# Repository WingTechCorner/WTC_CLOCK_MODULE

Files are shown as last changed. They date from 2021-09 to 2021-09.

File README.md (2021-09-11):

# WTC_CLOCK_MODULE

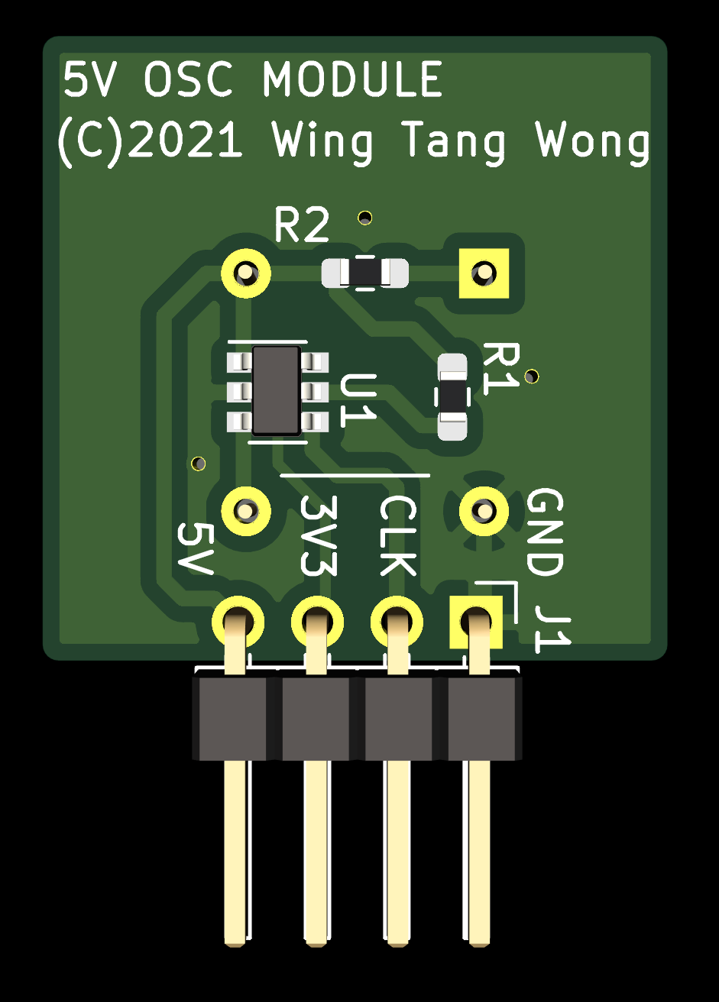
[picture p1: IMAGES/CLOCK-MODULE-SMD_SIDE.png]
SMD Side of Clock Module


# Project Purpose

* Make use of existing components I had in stock. In this case, a bunch of 40Mhz PLE(Plextronics) DIP-8, 4pin oscillators.
* Do voltage conversion from whatever the OSC uses to whatever the mainboard expects/users.
* Keep the footprint small.
* Use this as a sort of re-usable module going forward.

# Parts

| Part Count | Part Name | Package | Part | Usage | Notes |
| :----: | :---- | :---- | :---- | :---- | :---- |
| 1 | SN74LVC1T45 | SOT-23-6 | Single Channel Bidirectional Level Shifter | Takes the OSC clk_out and brings the voltage down to lower voltage. | 22 Ohm resistor has the DIR fixed so A goes to B only. |
| 2 | C23345 (LCSC Part Number) | 0603 SMD | 22 Ohm Resistor | Bridges signal pins to VCC | |
| 1 | PLE-SQ3300-40.00Mhz OSC | PDIP-8, 4pins, shortcan | 40Mhz 5V OSC | Plextronic's legacy/obsolete 40Mhz oscillator. | Generates a 5V, 40Mhz clock signal. Enable tied to VCC via resistor. Output goes to SN74LVC1T45 to have voltage reduced. |
| 1 | 1x4 header | 2.54mm 1x4 | Right angle male header 4 pins | Interface with parent module to provide a clock signal at the desired voltage levels. | Provides a "standard" way for me to add a clock source to another project board. Makes clock sources interchangable and/or re-usable. |

The assumption regarding the pinout of the OSC:

| Pin | Function |
| :-----: | :--- |
| 1 | Enable/Disable (current limit resistor tied to 5V) |
| 4 | GND |
| 5 | Clock Output |
| 8 | VCC (5V) |

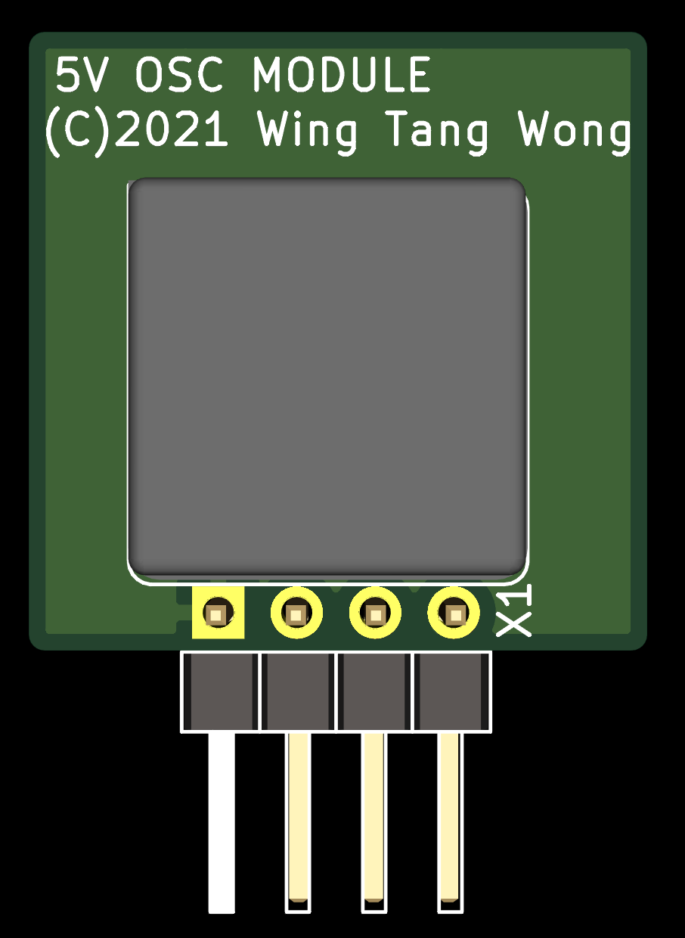
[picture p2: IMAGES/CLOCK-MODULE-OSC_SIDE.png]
OSC CAN Side of Clock Module


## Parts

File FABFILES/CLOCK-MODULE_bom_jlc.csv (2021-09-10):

Comment | Designator | Footprint | LCSC Part #
Conn_01x04 | J1 | PinHeader_1x04_P2.54mm_Horizontal | no_part_number
22 | R1,R2 | R_0603_1608Metric_Pad0.98x0.95mm_HandSolder | C23345
SN74LVC1T45DBV | U1 | SOT-23-6 | no_part_number
CXO_DIP8 | X1 | Oscillator_DIP-8 | C7843

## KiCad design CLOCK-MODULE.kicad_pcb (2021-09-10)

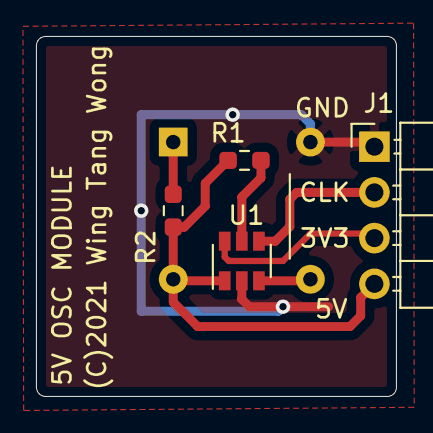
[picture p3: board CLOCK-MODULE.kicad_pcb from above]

Board: 2 copper layers, 20.0 x 20.0 mm, 5 parts (1 on the bottom side), 7 nets.

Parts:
J1: Conn_01x04; PinHeader_1x04_P2.54mm_Horizontal
R1, R2: 22; R_0603_1608Metric_Pad0.98x0.95mm_HandSolder
U1: SN74LVC1T45DBV; SOT-23-6
X1: CXO_DIP8; Oscillator_DIP-8

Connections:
/3V3: J1.3, U1.6
/5V: J1.4, R1.2, R2.2, U1.1, X1.8
/CLK-TO-LS: U1.3, X1.5
/CLK_OUT: J1.2, U1.4
/GND: J1.1, U1.2, X1.4
/OSC-EN: R2.1, X1.1
unnamed: R1.1, U1.5

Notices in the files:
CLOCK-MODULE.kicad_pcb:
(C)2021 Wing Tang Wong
